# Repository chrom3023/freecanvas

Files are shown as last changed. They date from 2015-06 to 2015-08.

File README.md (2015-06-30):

# freecanvas #

         ___             ___                      
        | __| _ ___ ___ / __|__ _ _ ___ ____ _ ___
        | _| '_/ -_) -_) (__/ _` | ' \ V / _` (_-<
        |_||_| \___\___|\___\__,_|_||_\_/\__,_/__/

FreeCanvas is a development environment for experimental art based on Arduino.

## ChangeLog ##

-   FreeCanvas usa [versionamiento semántico](http://semver.org).  
-   Fuente de alimentación implementada.  
-   Fuente con salidas independientes.  
-   Actualizado el procesador a *ATMEGA2560*.  
-   Conexión USB a través de *FT232*.  
-   Incorporado conector AVRISP de seis pines.  
-   Añadidos múltiples indicadores de estado.  
-   Añadida la posibilidad de conectar varios maestros en cascada.

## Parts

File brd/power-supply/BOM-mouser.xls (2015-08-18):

FreeCanvas:supply
Mouser REF | Fabr. N.º | Fabricante | Desc. | RoHS | Ciclo de vida | N.º Ref. del cliente | Ctd. pedido | Precio (EUR) | Ext.: (EUR)
594-NTCLE100E3473HB0 | NTCLE100E3473HB0 | Vishay | Termistores NTC 47Kohms 3% Radial | Conforme con RoHS por exención |  |  | 1 | 0,272 € | 0,27 €
538-22-23-2031 | 22-23-2031 | Molex | Alojamientos de cables y cabecera VERT PCB HDR 3P TIN FRICTION LOCK | Cumple RoHS |  |  | 2 | 0,188 € | 0,38 €
652-3266W-1-103LF | 3266W-1-103LF | Bourns | Resistencias eléctricos - Agujero pasante 1/4" 10Kohms 10% SQ W/Standoff Sealed | Conforme con RoHS por exención |  |  | 2 | 3,94 € | 7,88 €
512-LM358N | LM358N | Fairchild Semiconductor | Amplificadores operacionales - Op Amps Dual Operational Amp | Cumple RoHS |  |  | 1 | 0,483 € | 0,48 €
512-BC547BTA | BC547BTA | Fairchild Semiconductor | Transistores bipolares - BJT NPN 45V 100mA HFE/450 | Cumple RoHS |  |  | 2 | 0,201 € | 0,40 €
603-CFR-25JR-52-1K5 | CFR-25JR-52-1K5 | Yageo | Resistores de pel&iacute;cula de carb&oacute;n - a trav&eacute;s del orificio 1.5K ohm 1/4W 5% | Conforme con RoHS por exención |  |  | 1 | 0,101 € | 0,10 €
603-CFR-25JR-5247K | CFR-25JR-52-47K | Yageo | Resistores de pel&iacute;cula de carb&oacute;n - a trav&eacute;s del orificio 47K ohm 1/4W 5% | Conforme con RoHS por exención |  |  | 1 | 0,101 € | 0,10 €
603-CFR-25JR-522K2 | CFR-25JR-52-2K2 | Yageo | Resistores de pel&iacute;cula de carb&oacute;n - a trav&eacute;s del orificio 2.2K ohm 1/4W 5% | Conforme con RoHS por exención |  |  | 1 | 0,101 € | 0,10 €
603-CFR-25JB-1K0 | CFR-25JB-1K0 | Yageo | Resistores de pel&iacute;cula de carb&oacute;n - a trav&eacute;s del orificio | Cumple RoHS |  |  | 1 | 0,101 € | 0,10 €
140-RGA4R7M1HBK0511G | RGA4R7M1HBK-0511G | Lelon | Capacitadores electrolíticos de aluminio - Con patas 50V 4.7uF 105C 5x11mm | Cumple RoHS |  |  | 5 | 0,086 € | 0,43 €
588-RA-T2X-51E | RA-T2X-51E | Ohmite | Disipadores de calor HTSNK TO-220 218 247 BLK ANODIZED | Cumple RoHS |  |  | 4 | 2,06 € | 8,24 €
538-39880-0304 | 39880-0304 | Molex | Bloques terminales fijos LOW PROFILE 5.08 4 A W PROFILE 5.08 4 ASY | Cumple RoHS |  |  | 1 | 1,30 € | 1,30 €
538-39880-0303 | 39880-0303 | Molex | Bloques terminales fijos 3 CKT TERM. BLOCK 5.08mm | Cumple RoHS |  |  | 2 | 0,641 € | 1,28 €
562-703W-00/53 | 703W-00/53 | Qualtek | Módulos de entrada de corriente CA PCB Mount 7mm | Cumple RoHS |  |  | 1 | 0,90 € | 0,90 €
512-BC517D74Z | BC517_D74Z | Fairchild Semiconductor | Transistores Darlington NPN DAR 30V 1.2A | Cumple RoHS |  |  | 1 | 0,463 € | 0,46 €
655-RTE24005 | RTE24005 | TE Connectivity | Relés universales DPDT 8Amps | Cumple RoHS |  |  | 1 | 2,94 € | 2,94 €
691-2M1-SP1-T2B4M6RE | 2M1-SP1-T2-B4-M6RE | Carling Technologies | Conmutadores de palanca Mini Toggl SP PC MNT ON-NONE-ON | Cumple RoHS |  |  | 1 | 2,47 € | 2,47 €
530-5ST6.3-R | 5ST 6.3-R | Bel | Fusibles de cartucho | Cumple RoHS | Nuevo en Mouser |  | 2 | 0,206 € | 0,41 €
583-BR101 | BR101 | Rectron | Rectificadores de puente 10A 100V | Conforme con RoHS por exención |  |  | 1 | 1,21 € | 1,21 €
583-1N4007-T | 1N4007-T | Rectron | Rectificadores Vr/1000V Io/1A T/R | Conforme con RoHS por exención |  |  | 1 | 0,032 € | 0,03 €
647-UVZ1J102MHD | UVZ1J102MHD | Nichicon | Capacitadores electrolíticos de aluminio - Con patas 63volts 1000uF 16x25 20% 7.5LS | Cumple RoHS |  |  | 1 | 0,905 € | 0,91 €
647-UVK1H220MDD | UVK1H220MDD | Nichicon | Capacitadores electrolíticos de aluminio - Con patas 50volts 22uF 5x11 20% 2LS | Cumple RoHS |  |  | 2 | 0,101 € | 0,20 €
594-K104K15X7RF5UH5 | K104K15X7RF5UH5 | Vishay | Condensadores de cerámica multicapa (MLCC), con alimentación .1uF 50volts 10% 5.0mm X7R | Cumple RoHS | Nuevo en Mouser |  | 3 | 0,091 € | 0,27 €
293-1.8K-RC | 293-1.8K-RC | Xicon | Resistores de pel&iacute;cula de carb&oacute;n - a trav&eacute;s del orificio 1.8Kohms 0.05 | Cumple RoHS |  |  | 2 | 0,162 € | 0,32 €
603-CFR-25JR-523K3 | CFR-25JR-52-3K3 | Yageo | Resistores de pel&iacute;cula de carb&oacute;n - a trav&eacute;s del orificio 3.3K ohm 1/4W 5% | Conforme con RoHS por exención |  |  | 1 | 0,101 € | 0,10 €
279-CFR200J1K0 | CFR200J1K0 | TE Connectivity | Resistores de pel&iacute;cula de carb&oacute;n - a trav&eacute;s del orificio 1KOhm 2W 500PPM |  |  |  | 2 | 0,192 € | 0,38 €
603-CFR-25JR-52390R | CFR-25JR-52-390R | Yageo | Resistores de pel&iacute;cula de carb&oacute;n - a trav&eacute;s del orificio 390ohm 1/4W 5% | Conforme con RoHS por exención |  |  | 1 | 0,101 € | 0,10 €
603-CFR-25JR-52330R | CFR-25JR-52-330R | Yageo | Resistores de pel&iacute;cula de carb&oacute;n - a trav&eacute;s del orificio 330ohm 1/4W 5% | Conforme con RoHS por exención |  |  | 1 | 0,101 € | 0,10 €
603-CFR-25JR-52220R | CFR-25JR-52-220R | Yageo | Resistores de pel&iacute;cula de carb&oacute;n - a trav&eacute;s del orificio 220ohm 1/4W 5% | Conforme con RoHS por exención |  |  | 1 | 0,101 € | 0,10 €
863-MC78M05CTG | MC78M05CTG | ON Semiconductor | Reguladores de voltaje lineal 5V 500mA Positive | Cumple RoHS |  |  | 1 | 0,462 € | 0,46 €
511-LD1084V | LD1084V | STMicroelectronics | Reguladores de voltaje LDO 2.85-30V 5.0A Adj | Cumple RoHS |  |  | 2 | 1,39 € | 2,78 €
696-SLX-LX5093GD | SLX-LX5093GD | Lumex | LED estándar - Agujero pasante 5mm LED Lamps | Cumple RoHS |  |  | 1 | 0,069 € | 0,07 €
553-VPT30-3330 | VPT30-3330 | Triad Magnetics | Transformadores de potencia 30.0V CT @ 3.33A 15V @ 6.66A Parallel | Cumple RoHS |  |  | 1 | 39,02 € | 39,02 €
863-MC7815CTG | MC7815CTG | ON Semiconductor | Reguladores de voltaje lineal 15V 1A Postive | Cumple RoHS |  |  | 1 | 0,453 € | 0,45 €
863-MC7915ACTG | MC7915ACTG | ON Semiconductor | Reguladores de voltaje lineal 15V 1A Negative | Cumple RoHS |  |  | 1 | 0,525 € | 0,53 €
696-SLX-LX5093ID | SLX-LX5093ID | Lumex | LED estándar - Agujero pasante 5mm LED Lamps | Cumple RoHS |  |  | 3 | 0,059 € | 0,18 €
594-K103K15X7RF5UL2 | K103K15X7RF5UL2 | Vishay | Condensadores de cerámica multicapa (MLCC), con alimentación .01uF 50volts 10% 2.5mm X7R | Cumple RoHS | Nuevo en Mouser |  | 5 | 0,091 € | 0,46 €
647-UVR1V102MHD1TO | UVR1V102MHD1TO | Nichicon | Capacitadores electrolíticos de aluminio - Con patas 1000uF 35V 85c | Cumple RoHS |  |  | 4 | 0,453 € | 1,81 €
576-64600001223 | 64600001223 | Littelfuse | Portafusibles ACS 5X20MM BLOCK 3.2MM PINS | Cumple RoHS |  |  | 2 | 0,72 € | 1,44 €

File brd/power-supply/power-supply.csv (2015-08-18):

Source: | /home/kwendenarmo/git-repos/local/synusia/freecanvas/brd/power-supply/power-supply.sch
Date: | mar 18 ago 2015 19:39:24 CEST
Tool: | Eeschema 0.201508110901+6083~28~ubuntu14.04.1-product
Generator: | /usr/share/doc/kicad/scripts/bom-in-python/bom_csv_grouped_by_value_with_fp.py
Component Count: | 68
Ref | Qnty | Value | Cmp name | Footprint | Description | Vendor
C3, | 1 | 1000uF | CP | Capacitors_ThroughHole:C_Radial_D16_L25_P7.5 | Polarised capacitor | 647-UVZ1J102MHD
C4, C18, C19, C1, C5, | 5 | 10nF | C | Capacitors_ThroughHole:C_Disc_D3_P2.5 | Unpolarized capacitor | 594-K103K15X7RF5UL2
C6, C10, C7, C11, | 4 | 1000uF | CP | Capacitors_ThroughHole:C_Radial_D12.5_L25_P5 | Polarised capacitor | 647-UVR1V102MHD1TO
C8, C9, | 2 | 22uF | CP | Capacitors_ThroughHole:C_Radial_D5_L11_P2 | Polarised capacitor | 647-UVK1H220MDD
C12, C13, C16, C17, C2, | 5 | 4.7uF | CP | Capacitors_ThroughHole:C_Radial_D5_L11_P2 | Polarised capacitor | 140-RGA4R7M1HBK0511G
C14, C15, C20, | 3 | 100nF | C | Capacitors_ThroughHole:C_Disc_D3_P2.5 | Unpolarized capacitor | 594-K104K15X7RF5UH5
D1, D2, D6, | 3 | RED | LED-RESCUE-power-supply | LEDs:LED-5MM |  | 696-SLX-LX5093ID
D3, | 1 | BR101 | Diode_Bridge | asrdi-diode:BR-10 | Diode bridge | 583-BR101
D4, | 1 | GREEN | LED-RESCUE-power-supply | LEDs:LED-5MM |  | 696-SLX-LX5093GD
D5, | 1 | 1N4007 | D | Diodes_ThroughHole:Diode_DO-41_SOD81_Horizontal_RM10 | Diode | 583-1N4007-T
F1, F2, | 2 | 6.3A | FUSE | asrdi-fuse:Fuseholder5x20-littelfuse646 |  | 576-64600001223
HS3, HS4, HS1, HS2, | 4 | HEATSINK | HEATSINK | asrdi-heatsink:RA-T2X-xxE |  | 588-RA-T2X-51E
J1, | 1 | IEC C13 | CONN_01X03 | asrdi-conn:703W-0053 |  | 562-703W-00/53
J2, | 1 | PE | CONN_01X01 | Divers:douille_4mm
J3, | 1 | MAIN OUT | CONN_01X04 | asrdi-conn:39880-0304 |  | 538-39880-0304
J4, | 1 | CONTROL | CONN_01X03 | asrdi-conn:39880-0303 |  | 538-39880-0303
J6, J5, | 2 | FAN | CONN_01X03 | Socket_Strips:Socket_Strip_Straight_1x03 |  | 538-22-23-2031
J7, | 1 | DUAL OUT | CONN_01X03 | asrdi-conn:39880-0303 |  | 538-39880-0303
K1, | 1 | RTE24005 | RTE24xxx | Relays_ThroughHole:Relay_DPDT_Schrack-RT2_RM5mm |  | 655-RTE24005
Q2, Q1, | 2 | BC547 | BC547 | Housings_TO-92:TO-92_Inline_Wide | 45V Vce, 0.1A Ic, NPN, Small Signal Transistor, TO-92 | 512-BC547BTA
Q3, | 1 | BC517 | BC517 | Housings_TO-92:TO-92_Inline_Wide | 30V Vce, 1A Ic, NPN Darlington Transistor, TO-92 | 512-BC517D74Z
R2, R1, | 2 | 1k8 | R | Resistors_ThroughHole:Resistor_Horizontal_RM15mm | Resistor | 293-1.8K-RC
R3, | 1 | 330R | R | Resistors_ThroughHole:Resistor_Horizontal_RM10mm | Resistor | 603-CFR-25JR-52330R
R4, | 1 | 390R | R | Resistors_ThroughHole:Resistor_Horizontal_RM10mm | Resistor | 603-CFR-25JR-52390R
R5, | 1 | 1k | R | Resistors_ThroughHole:Resistor_Horizontal_RM10mm | Resistor | 603-CFR-25JB-1K0
R6, | 1 | 3k3 | R | Resistors_ThroughHole:Resistor_Horizontal_RM10mm | Resistor | 603-CFR-25JR-523K3
R7, | 1 | 2k2 | R | Resistors_ThroughHole:Resistor_Horizontal_RM10mm | Resistor | 603-CFR-25JR-522K2
R8, R9, | 2 | 1k | R | Resistors_ThroughHole:Resistor_Horizontal_RM20mm | Resistor | 279-CFR200J1K0
R10, | 1 | 220R | R | Resistors_ThroughHole:Resistor_Horizontal_RM10mm | Resistor | 603-CFR-25JR-52220R
R11, | 1 | 47k | R | Resistors_ThroughHole:Resistor_Horizontal_RM10mm | Resistor | 603-CFR-25JR-5247K
R12, | 1 | 47k NTC | RVAR | Capacitors_ThroughHole:C_Disc_D3_P2.5 |  | 594-NTCLE100E3473HB0
R14, | 1 | 1k5 | R | Resistors_ThroughHole:Resistor_Horizontal_RM10mm | Resistor | 603-CFR-25JR-52-1K5
R15, R13, | 2 | 10k | R | Resistors_ThroughHole:Resistor_Horizontal_RM10mm | Resistor | 603-CFR-25JR-5210K
RV2, RV1, | 2 | 10k | POT | Potentiometers:Potentiometer_Bourns_3296Y_3-8Zoll_Angular_ScrewUp | Potentionmetre | 652-3266W-1-103LF
SW1, | 1 | SWITCH ON | SPST | asrdi-switch:Carling-2M1-SP1-T2-B4-M6RE | Interrupteur simple | 691-2M1-SP1-T2B4M6RE
T1, | 1 | 2x15 100VA | TRANSFO_3 | asrdi-trafo:VPT30-3330 |  | 553-VPT30-3330
U1, | 1 | LM78M05CT | LM78M05CT | Power_Integrations:TO-220 | Positive 0.5A 35V Linear Regulator, Fixed Output 5V, TO-220 | 863-MC78M05CTG
U2, U3, | 2 | LM1084IT-ADJ/NOPB | LM1084IT-ADJ/NOPB | Power_Integrations:TO-220 | LM1084IT, 5A 29V Adjustable Linear Regulator, TO-220 | 511-LD1084V
U4, | 1 | LM7815ACT | LM7815ACT | Power_Integrations:TO-220 | Positive 1A 35V Linear Regulator, Fixed Output 5V, TO-220 | 863-MC7815CTG
U5, | 1 | LM7915CT | LM7915CT | Power_Integrations:TO-220 | Negative 1A 35V Linear Regulator, Fixed Output 5V, TO-220 | 863-MC7915ACTG
U6, | 1 | LM358 | LM358 | Housings_DIP:DIP-8__300_ELL | Dual Op amp (low power) | 512-LM358N

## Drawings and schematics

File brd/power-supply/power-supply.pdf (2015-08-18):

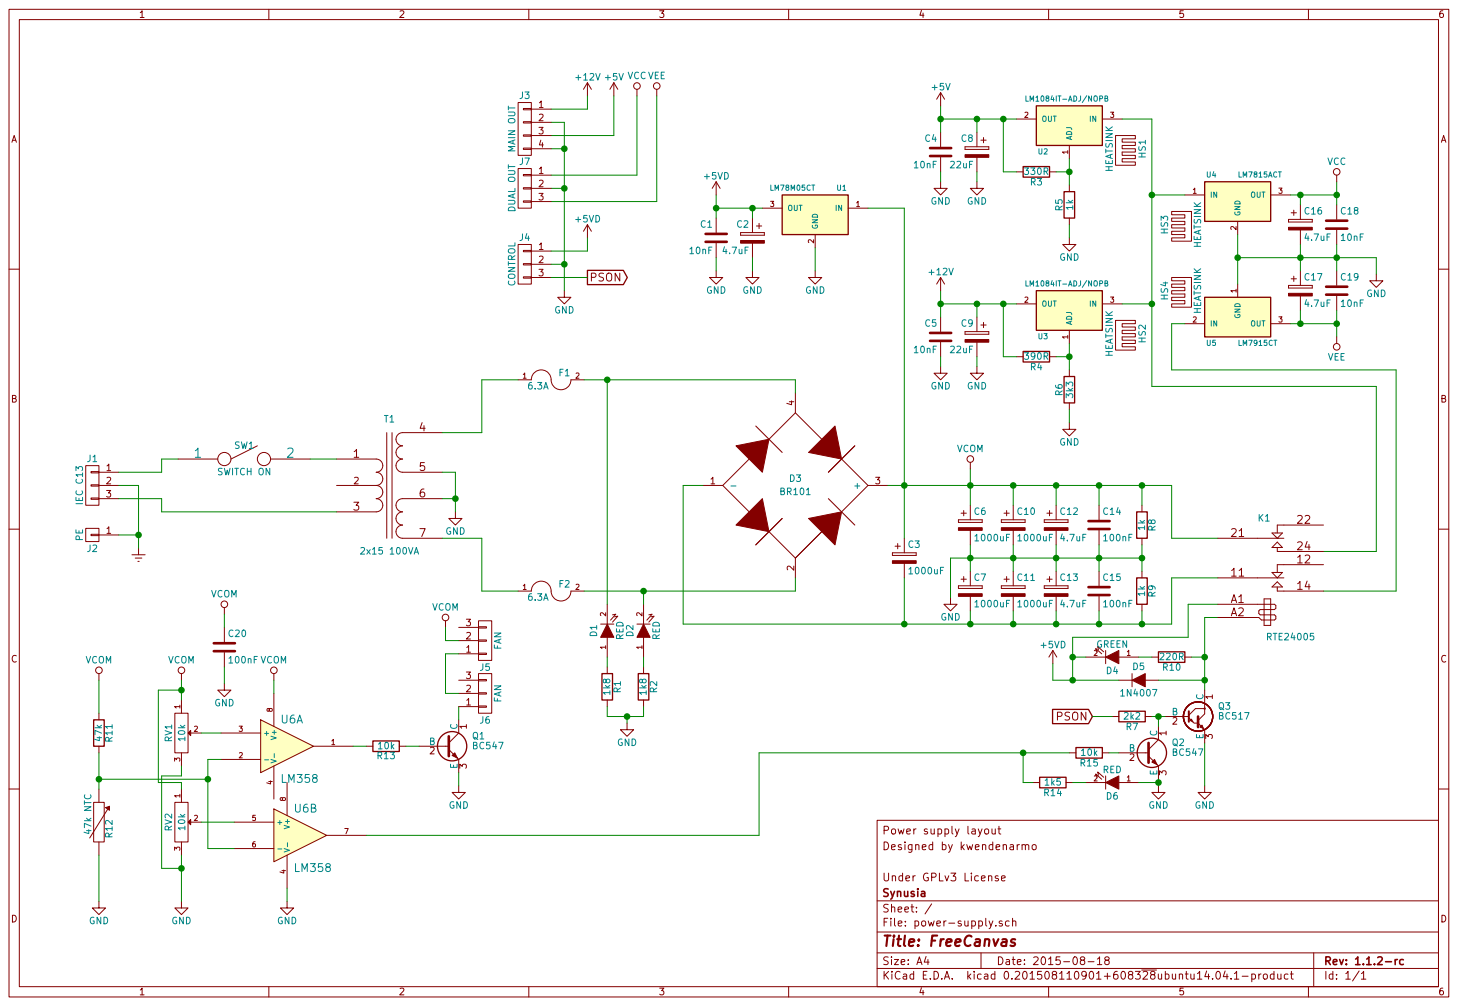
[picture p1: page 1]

File: power-supply.sch Sheet: / Synusia Under GPLv3 License Designed by kwendenarmo

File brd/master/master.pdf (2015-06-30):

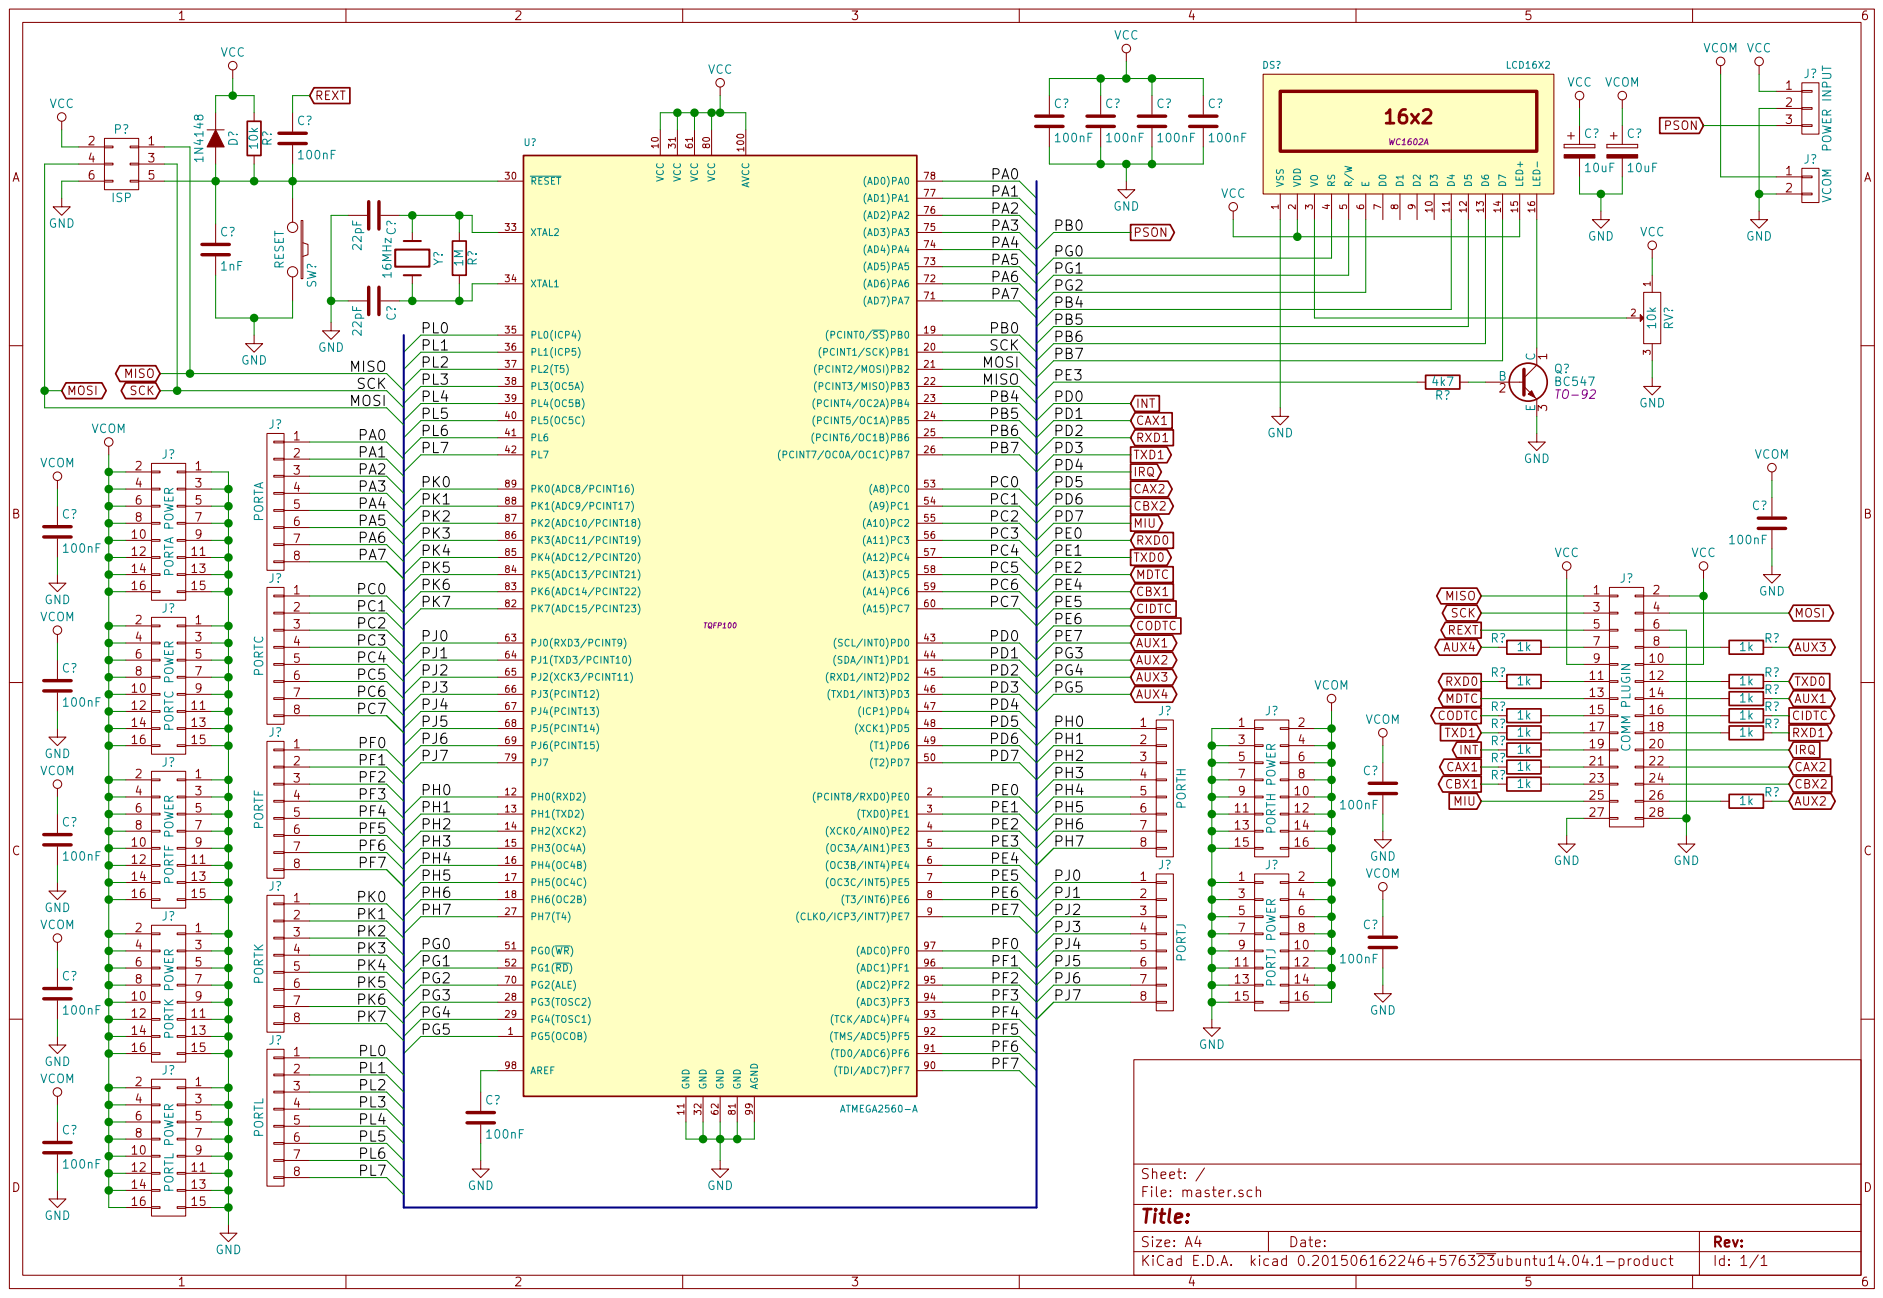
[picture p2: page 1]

PG4(TOSC1) 29
Id: 1/1 Title: File: master.sch Sheet: / PG5(OCOB) 1

14 | 13
16 | 15

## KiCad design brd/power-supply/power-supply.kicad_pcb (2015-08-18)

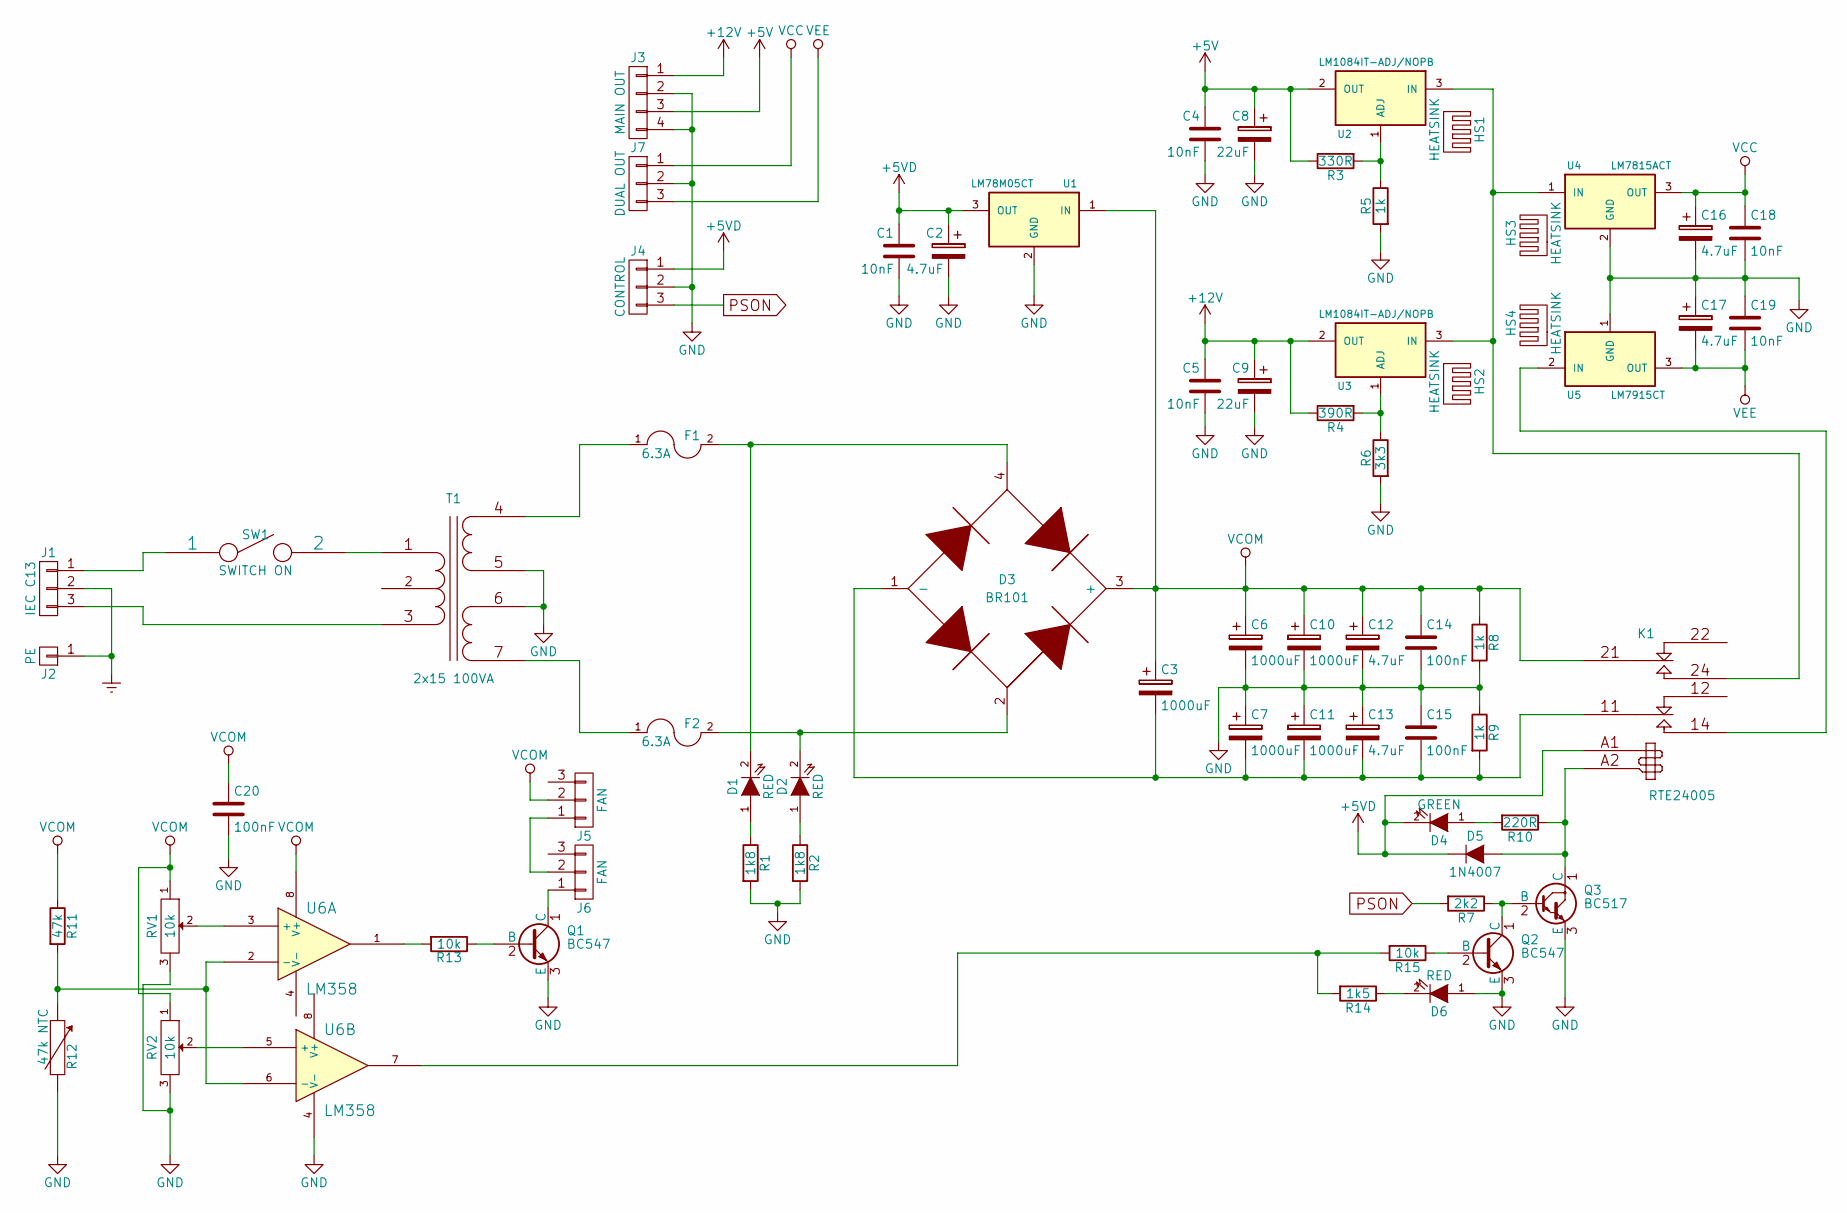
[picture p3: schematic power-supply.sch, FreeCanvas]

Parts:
C1, C4, C5, C18, C19: 10nF; C_Disc_D3_P2.5
C2, C12, C13, C16, C17: 4.7uF; C_Radial_D5_L11_P2
C3: 1000uF; C_Radial_D16_L25_P7.5
C6, C7, C10, C11: 1000uF; C_Radial_D12.5_L25_P5
C8, C9: 22uF; C_Radial_D5_L11_P2
C14, C15, C20: 100nF; C_Disc_D3_P2.5
D1, D2, D6: RED; LED-5MM
D3: BR101; BR-10
D4: GREEN; LED-5MM
D5: 1N4007; Diode_DO-41_SOD81_Horizontal_RM10
F1, F2: 6.3A; Fuseholder5x20-littelfuse646
HS1, HS2, HS3, HS4: HEATSINK; RA-T2X-xxE
J1: IEC C13; 703W-0053
J2: PE; douille_4mm
J3: MAIN OUT; 39880-0304
J4: CONTROL; 39880-0303
J5, J6: FAN; Socket_Strip_Straight_1x03
J7: DUAL OUT; 39880-0303
K1: RTE24005; Relay_DPDT_Schrack-RT2_RM5mm
Q1, Q2: BC547; TO-92_Inline_Wide
Q3: BC517; TO-92_Inline_Wide
R1, R2: 1k8; Resistor_Horizontal_RM15mm
R3: 330R; Resistor_Horizontal_RM10mm
R4: 390R; Resistor_Horizontal_RM10mm
R5: 1k; Resistor_Horizontal_RM10mm
R6: 3k3; Resistor_Horizontal_RM10mm
R7: 2k2; Resistor_Horizontal_RM10mm
R8, R9: 1k; Resistor_Horizontal_RM20mm
R10: 220R; Resistor_Horizontal_RM10mm
R11: 47k; Resistor_Horizontal_RM10mm
R12: 47k NTC; C_Disc_D3_P2.5
R13, R15: 10k; Resistor_Horizontal_RM10mm
R14: 1k5; Resistor_Horizontal_RM10mm
RV1, RV2: 10k; Potentiometer_Bourns_3296Y_3-8Zoll_Angular_ScrewUp
SW1: SWITCH ON; Carling-2M1-SP1-T2-B4-M6RE
T1: 2x15 100VA; VPT30-3330
U1: LM78M05CT; TO-220
U2, U3: LM1084IT-ADJ/NOPB; TO-220
U4: LM7815ACT; TO-220
U5: LM7915CT; TO-220
U6: LM358; DIP-8__300_ELL

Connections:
+5V: C4.1, C8.1, J3.3, R3.1, U2.2 (OUT)
+5VD: C1.1, C2.1, D4.2 (K), D5.1 (K), J4.1, K1.A1, U1.3 (OUT)
+12V: C5.1, C9.1, J3.1, R4.1, U3.2 (OUT)
Earth: J1.2, J2.1
GND: C1.2, C2.2, C4.2, C5.2, C6.2, C7.1, C8.2, C9.2, C10.2, C11.1, C12.2, C13.1, C14.2, C15.1, C16.2, C17.1, C18.2, C19.1, C20.2, D6.1 (A), J3.2, J3.4, J4.2, J7.2, Q1.3 (E), Q2.3 (E), Q3.3 (E), R1.2, R2.2, R5.2, R6.2, R8.2, R9.1, R12.2, RV1.3, RV2.3, T1.5 (OUT1B), T1.6 (OUT2A), U1.2 (GND), U4.2 (GND), U5.1 (GND), U6.4 (V-)
unnamed: C3.2, C7.2, C11.2, C13.2, C15.2, D3.1 (-), K1.11, R9.2
unnamed: D1.1 (A), R1.1
unnamed: D1.2 (K), D3.4, F1.2
unnamed: D2.1 (A), R2.1
unnamed: D2.2 (K), D3.2, F2.2
unnamed: D4.1 (A), R10.2
unnamed: D5.2 (A), K1.A2, Q3.1 (C), R10.1
unnamed: D6.2 (K), R14.1
unnamed: F1.1, T1.4 (OUT1A)
unnamed: F2.1, T1.7 (OUT2B)
unnamed: J1.1, SW1.1
unnamed: J1.3, T1.3 (IN-)
unnamed: J5.1, J6.2
unnamed: J6.1, Q1.1 (C)
unnamed: K1.14, U5.2 (IN)
unnamed: K1.24, U2.3 (IN), U3.3 (IN), U4.1 (IN)
unnamed: Q1.2 (B), R13.1
unnamed: Q2.1 (C), Q3.2 (B), R7.1
unnamed: Q2.2 (B), R15.1
unnamed: R3.2, R5.1, U2.1 (ADJ)
unnamed: R4.2, R6.1, U3.1 (ADJ)
unnamed: R11.2, R12.1, U6.2 (-), U6.6 (-)
unnamed: R13.2, U6.1
unnamed: R14.2, R15.2, U6.7
unnamed: RV1.2, U6.3 (+)
unnamed: RV2.2, U6.5 (+)
unnamed: SW1.2, T1.1 (IN+)
PSON: J4.3, R7.2
VCC: C16.1, C18.1, J7.1, U4.3 (OUT)
VCOM: C3.1, C6.1, C10.1, C12.1, C14.1, C20.1, D3.3 (+), J5.2, K1.21, R8.1, R11.1, RV1.1, RV2.1, U1.1 (IN), U6.8 (V+)
VEE: C17.2, C19.2, J7.3, U5.3 (OUT)

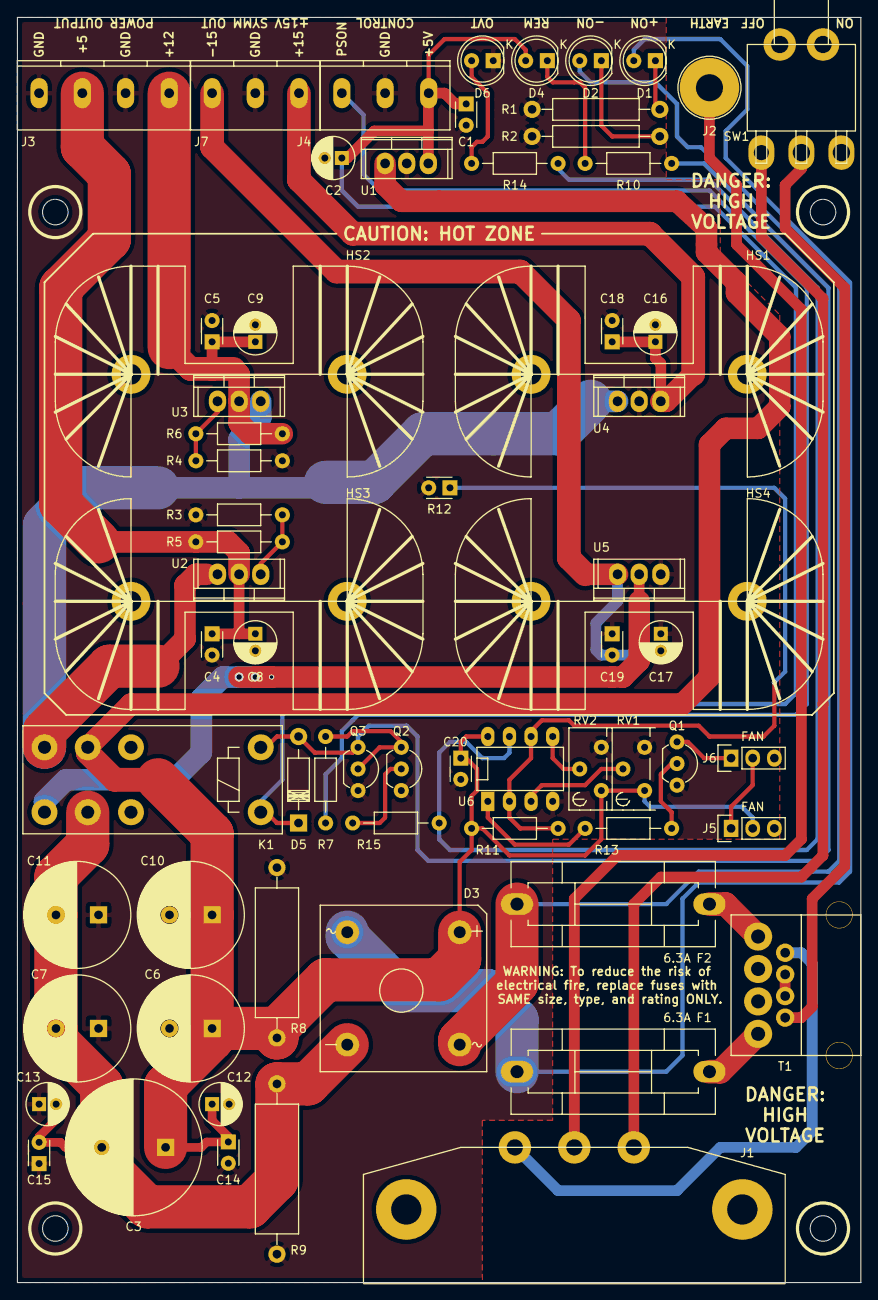
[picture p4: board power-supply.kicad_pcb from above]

Board: 2 copper layers, 99.1 x 148.6 mm, 68 parts (0 on the bottom side), 36 nets.

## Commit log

2015-06-30 subida archivos
    [master.sch, power-supply.csv, power-supply.sch]
2015-08-18 version 1.1.2-rc añadido bom y referencias mouser en esquemático, corregido fallo de máscara en pcb y generado gerber
    [BOM-mouser.xls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]
